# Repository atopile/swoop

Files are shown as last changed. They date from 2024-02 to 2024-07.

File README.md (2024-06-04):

# swoop

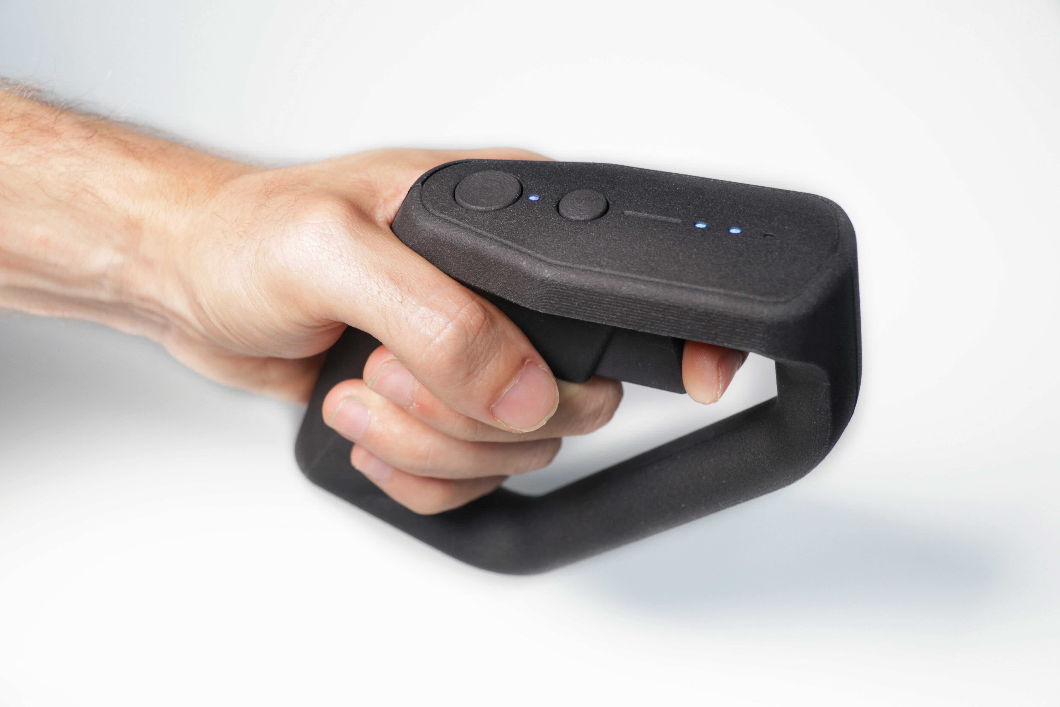
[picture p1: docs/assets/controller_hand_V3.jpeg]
controller and hand


<div align="center">
    <a href="#">
        
    </a>
    <a href="#">
        
    </a>
    <a href="#">
        
    </a>
    <a href="#">
        
    </a>
    <a href="#">
        
    </a>
</div>

## What is swoop🛫?

With swoop, you can fly remote controlled aircraft with the motion of your hand. It's especially fun when flying FPV because the motion of your remote precisely maps to the aircraft.

## Build your own controller

This project is fully open source and designed with [atopile](https://github.com/atopile/atopile), a new language and compiler to design electronics with code.

**Latest auto-generated artifacts**

[Electronics: Gerbers, Bill of material, position files](https://atopile.s3.amazonaws.com/swoop/electronics/electronics_build_artifacts.zip)

[Firmware](https://atopile.s3.amazonaws.com/swoop/firmware/firmware_build_artifacts.zip)

[3D Files (STL, STEP files in the future)](https://atopile.s3.amazonaws.com/swoop/mechanics/3D_files.zip)

**Atopile code**

The atopile entry point is located [here](https://github.com/atopile/swoop/blob/main/elec/src/swoop.ato). Clone the repository and [install atopile](https://atopile.io/getting-started/) if you'd like to explore further.

## Here is how it works:

The three rotation axis, yaw, pitch, roll of the remote each control the same channel on your aircraft. If you tilt your remote to a certain angle, your aircraft will rotate in that same direction with a certain rotational speed. That's what makes this controller so intuitive to use!
To start using the remote, simply double click the arming button (the larger button). This will zero the controller to the current position and start streaming the control outputs to the receiver.

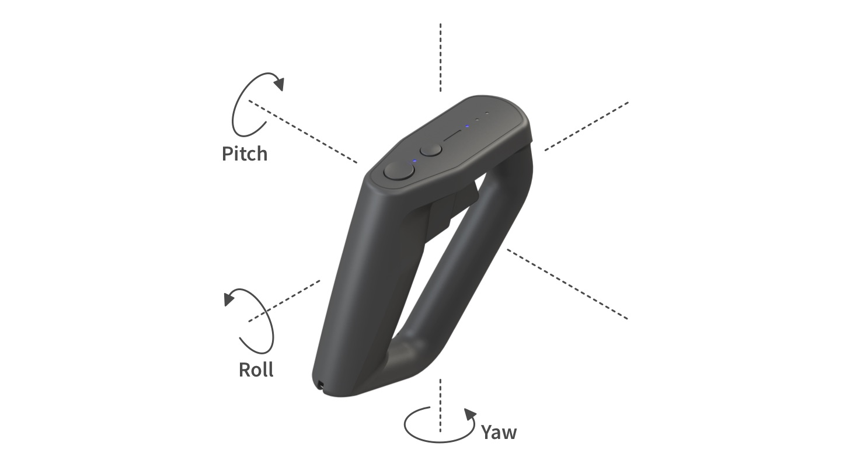
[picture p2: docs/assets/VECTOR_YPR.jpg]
yaw, pitch, roll


To control the throttle, which is your aircraft's motor power, simply press the trigger. Inside the controller, a hall sensor precisely keeps track of the trigger position. This makes for a total of four control inputs with yaw, pitch, roll and throttle.

The smaller button on the remote let's you switch the flight mode. Pretty handy to tweak how your aircraft reacts to your control inputs!

Lastly, the remote has an integrated transceiver from the popular open source ExpressLRS project, which makes it compatible with any of their receivers!

## Feature list

Here is what we are planning for this controller:

- Yaw, pitch and roll control angles from the motion of your hand
- Throttle control through the trigger
- Arming button (sets zero position and turn control inputs on/off)
- Flight mode button
- Embedded ExpressLRS transceiver
- Rechargeable over USB-C

## Documentation & Status

We will share documentation once we've made more progress on the project development. For current status, checkout the [product page](https://atopile.io/swoop/).

## Join us!

### Discord

If you are curious about the project, join us on the [atopile discord server](https://discord.gg/nr5V3QRUd3).

### Contributing

If you would like to contribute on atopile, here is what you will need:

For electronics:
- [atopile](https://atopile.io): here is a guide on how to install it: https://atopile.io/getting-started/
- [ExpressLRS](https://www.expresslrs.org): ELRS is an open source long range communication protocol for remote controlled aircraft. If you would like to test the remote, having compatible hardware will help!

For firmware:
- [PlatformIO](https://platformio.org): Cross platform firmware development toolchain
- [CRSF for Arduino](https://github.com/ZZ-Cat/CRSFforArduino): Implementation of the CRSF protocol for arduino. We'll be running this library to stream data from the controller microcontroller to the EzpressLRS module
- [ExpressLRS](https://www.expresslrs.org): ELRS is an open source long range communication protocol for remote controlled aircraft. Their firmware will be flashed on the embedded ESP32S2 module within the controller.

## Happy Flying!

swoop_test

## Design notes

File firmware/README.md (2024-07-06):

# Setup instructions

## Windows

1. Install git by running the following command in a terminal winow: `winget install Git.Git`
1. [Enable long paths both on the operating system and git level](https://arduino-pico.readthedocs.io/en/latest/platformio.html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)
1. Clone the repository e.g. using `git clone https://github.com/atopile/swoop.git`
1. Install [Visual Studio Code](https://code.visualstudio.com/)
1. Install [PlatformIO IDE Extension](https://platformio.org/install/ide?install=vscode)
1. Reopen Visual Studio Code and open the folder of the repository, it will install all dependencies
1. Donwload [Zadig](https://zadig.akeo.ie/) and install the WinUSB driver for the connected "RP2 Boot" device when Swoop is connected over USB
Zadig window Installing WinUSB using Zadig
1. At the bottom left of the window you find buttons for building, uploading, serial telemetry

## Mac

1. Install git e.g. via [Homebrew](https://brew.sh/) using `brew install git` ([formula](https://formulae.brew.sh/formula/git))
1. Clone Repository ´git clone https://github.com/atopile/swoop.git´
1. Install [Visual Studio Code](https://code.visualstudio.com/) Hombrew command: `brew install --cask visual-studio-code` ([formula](https://formulae.brew.sh/cask/visual-studio-code))
1. Install [PlatformIO Visual Studio Code Extension](https://marketplace.visualstudio.com/items?itemName=platformio.platformio-ide)
1. Reopen Visual Studio Code and open the folder of the repository, it will install all dependencies
1. At the bottom left of the window you find buttons for building, uploading, serial telemetry

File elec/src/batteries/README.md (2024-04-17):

# Battery connections

## Installation
Run in the terminal:

```ato install batteries```

Add the battery connectors to your project:

```import BatteryJST from "batteries/batteries.ato"```
```import Battery18650 from "batteries/batteries.ato"```
```import BatteryCR2032 from "batteries/batteries.ato"```

Feel free to add other battery modules to the repo through a pull request!

## 18650 holder
![18650 holder](https://assets.lcsc.com/images/lcsc/900x900/20230121_MYOUNG-BH-18650-A1AJ005_C5290176_front.jpg)

## JST GH Connector
![jst_gh](https://assets.lcsc.com/images/lcsc/900x900/20230108_JST-S2B-PH-SM4-TB-LF-SN_C295747_front.jpg)

## Coin cell holder
![coin cell](https://assets.lcsc.com/images/lcsc/900x900/20230105_MYOUNG-BS-02-A1AJ010_C5239862_front.jpg)

## Features

- **Power interface:** Hook the battery up to your circuit

## Documentation & Resources

- [LCSC part number for the 18650 holder](https://www.lcsc.com/product-detail/Battery-Connectors_MYOUNG-BH-18650-A1AJ005_C5290176.html)
- [LCSC part number for the JST GH connector](https://www.lcsc.com/product-detail/Wire-To-Board-Wire-To-Wire-Connector_JST-S2B-PH-SM4-TB-LF-SN_C295747.html)
- [LCSC part number for the coin cell holder](https://www.lcsc.com/product-detail/Battery-Connectors_MYOUNG-BS-02-A1AJ010_C5239862.html)

## Contributing

Contribute to this package using pull requests.

## License

This battery connector module is provided under the [MIT License](https://opensource.org/license/mit/).

## Contact

For further inquiries or support, please contact me at [narayan@atopile.io](mailto:narayan@atopile.io).

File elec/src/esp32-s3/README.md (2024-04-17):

## Overview

The ESP32-S3 is a powerful, versatile microcontroller designed for IoT applications. It features dual-core Xtensa LX7 processors, Wi-Fi and Bluetooth 5 connectivity, rich I/O capabilities, and enhanced security features, making it ideal for smart home devices, wearable electronics, and automated systems requiring efficient processing and wireless communication.

ESP32-S3

## Usage Example

```
import ESP32 from "esp32/esp32.ato"
import Power from "generics/interfaces.ato"

module my_project:
   power3v3 = new Power
   micro = new ESP32
   micro.power ~ power3v3

```

## Features
Power interface: 3.3V input
SPI interface: 4-wire SPI
I2C interface
JTAG interface

## Contributing
Contribute to this package using pull requests.

## License
This battery connector module is provided under the MIT License.

## Contact
For further inquiries or support, please contact me at narayan@atopile.io.

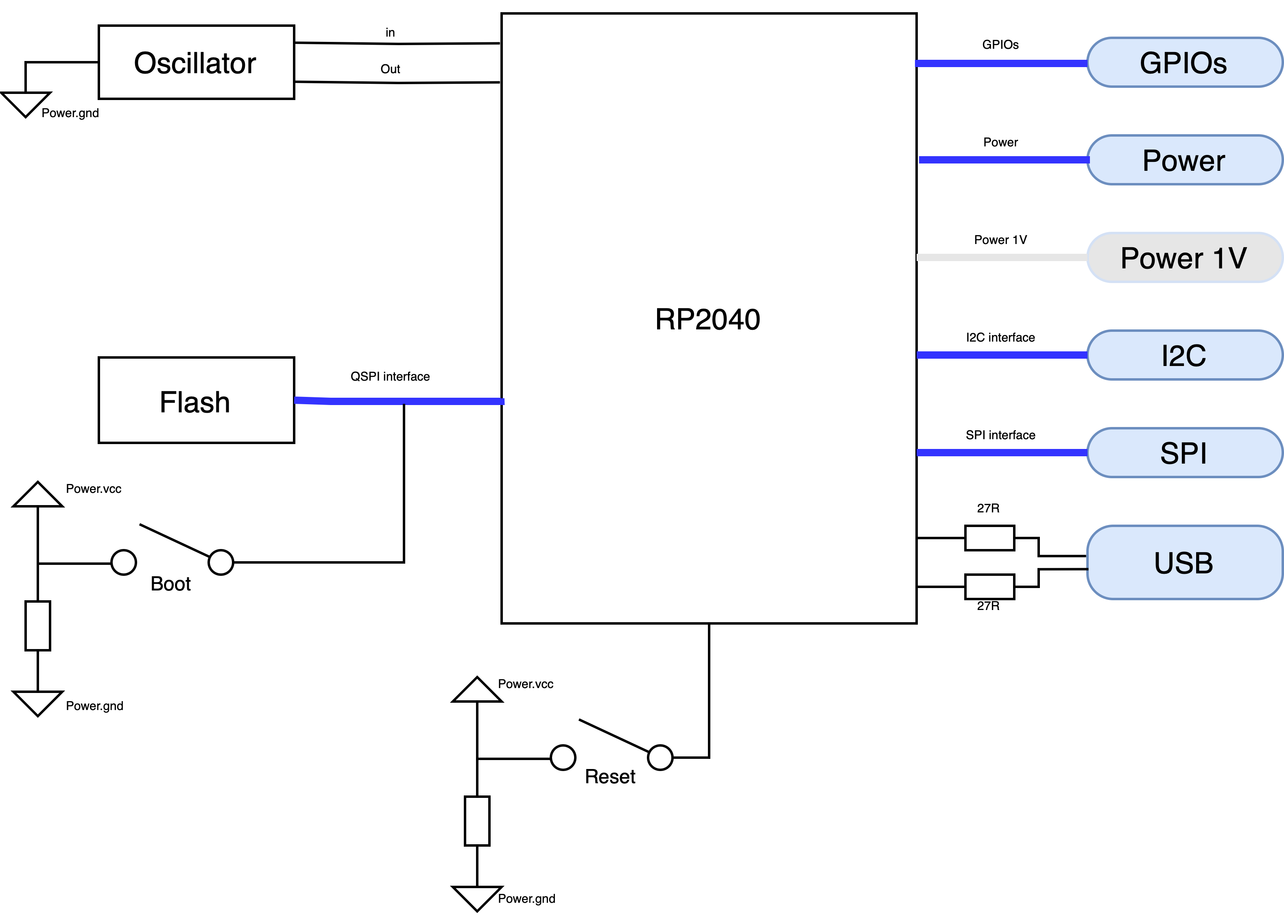
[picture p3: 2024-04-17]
elec/src/rp2040/docs/rp2040Kit.png

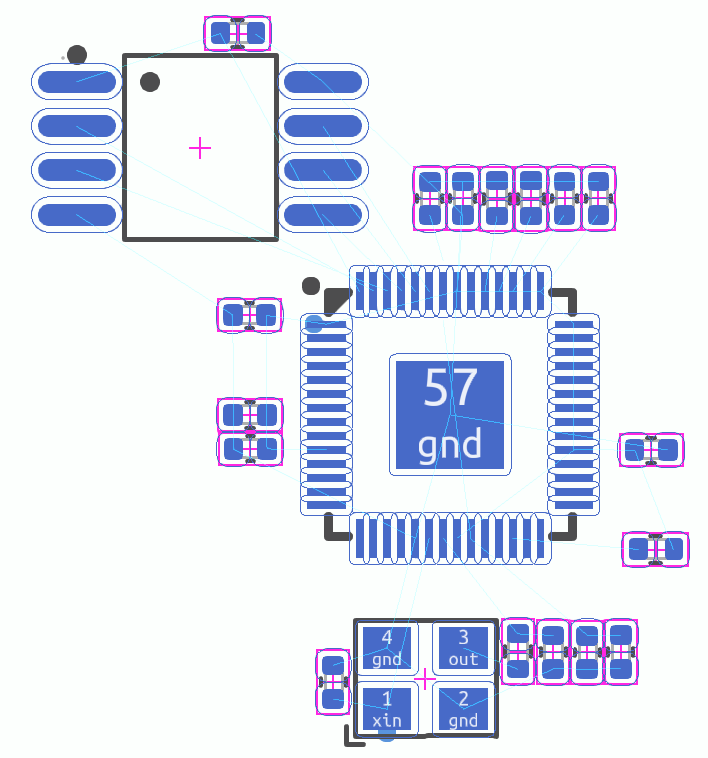
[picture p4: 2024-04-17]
elec/src/rp2040/docs/layout-example.png

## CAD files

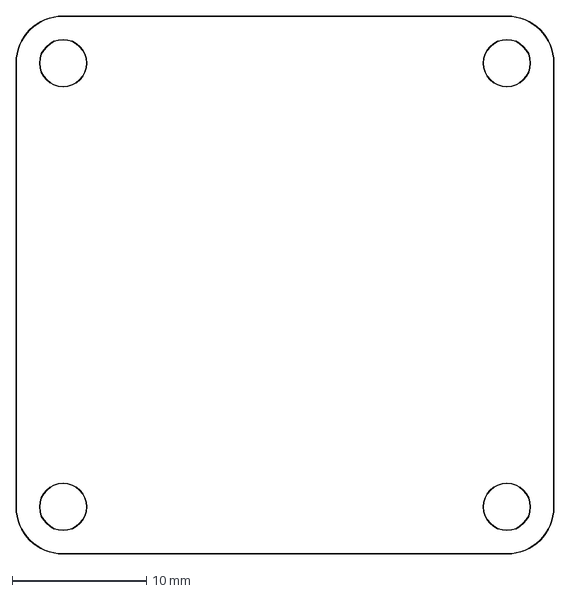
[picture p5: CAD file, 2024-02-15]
elec/src/drv5053raqdbzr/mech/template_outline.dxf
40.0 x 40.0 mm

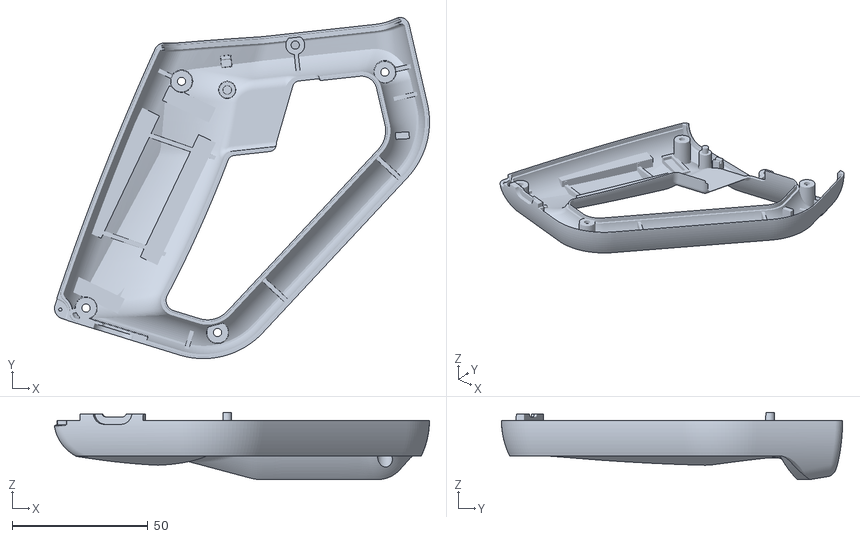
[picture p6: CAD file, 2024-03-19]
mech/shell_left.stl
138.2 x 125.8 x 24.9

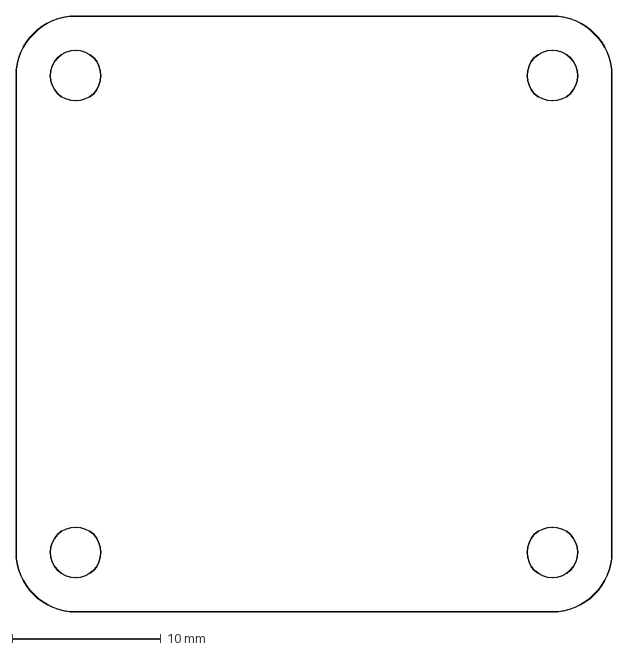
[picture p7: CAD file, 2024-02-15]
elec/src/drv5053raqdbzr/mech/template_40x40.dxf
40.0 x 40.0 mm

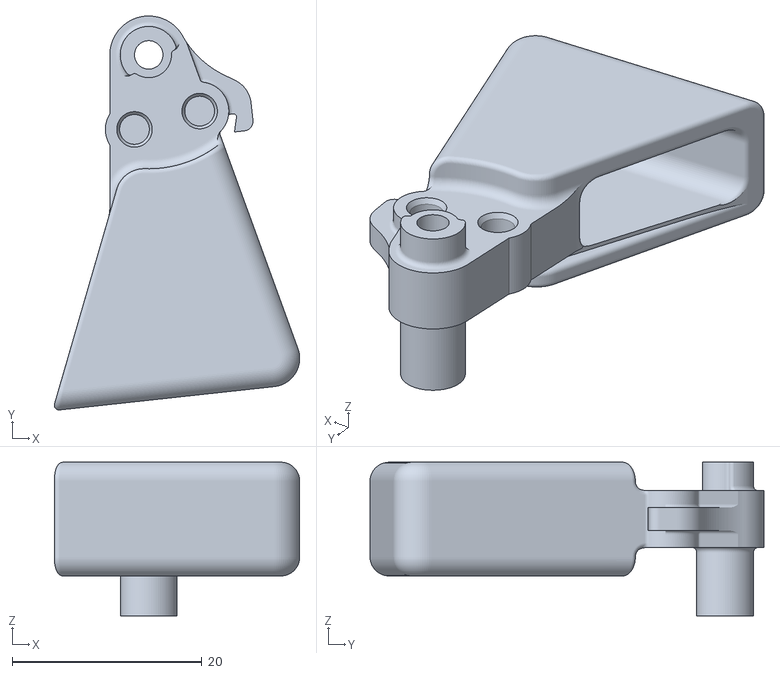
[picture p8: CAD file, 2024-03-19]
mech/trigger.stl
25.9 x 41.5 x 16.2

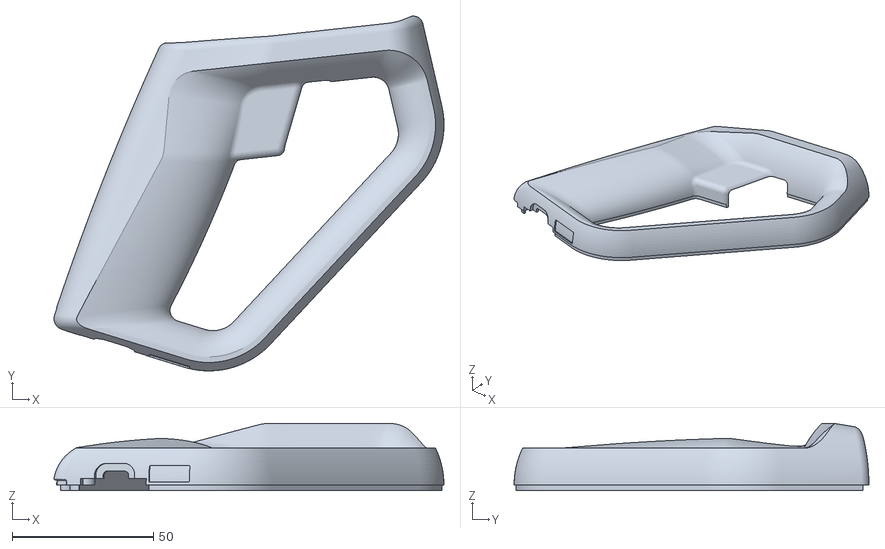
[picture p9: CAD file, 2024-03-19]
mech/Shell_right.stl
138.2 x 125.8 x 23.9

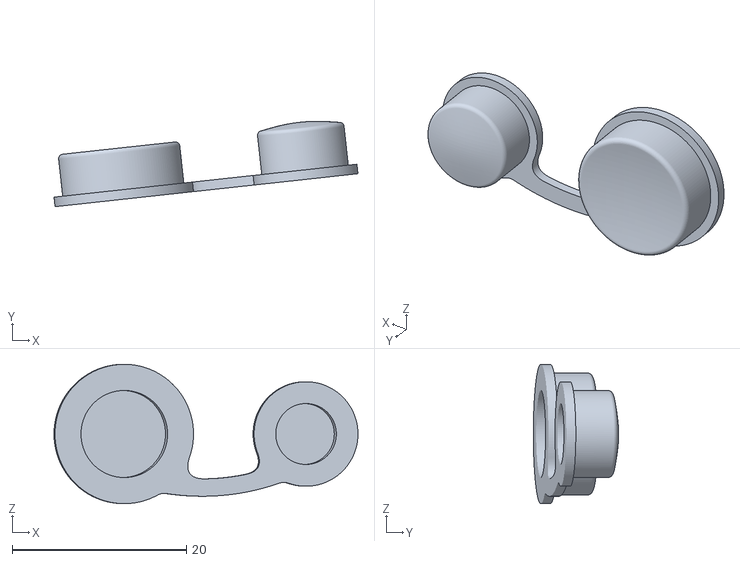
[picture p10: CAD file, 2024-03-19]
mech/buttons.stl
34.9 x 9.80 x 16.0

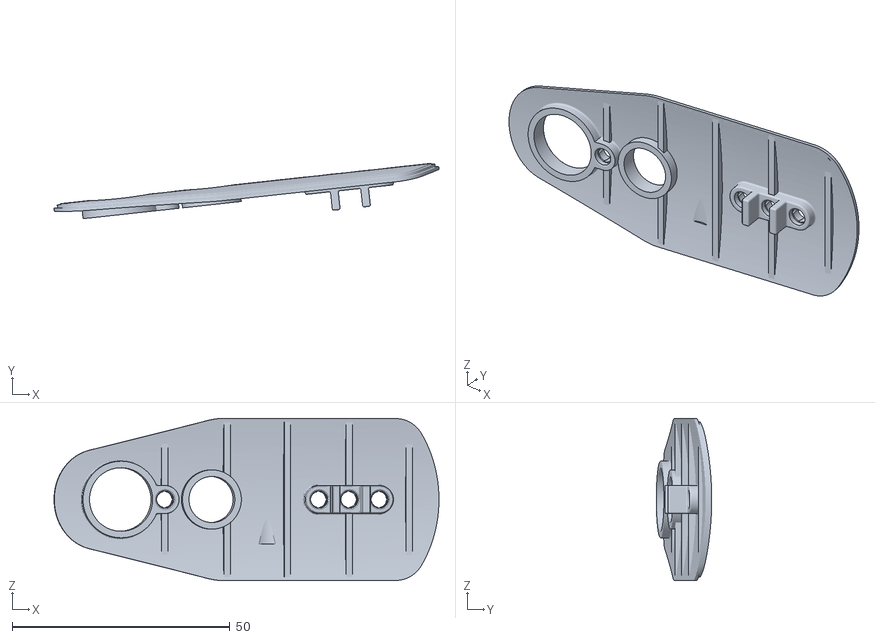
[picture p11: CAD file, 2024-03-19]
mech/top.stl
88.5 x 12.7 x 37.3

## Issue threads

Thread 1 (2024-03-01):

I2C Pull-up is too soft

mawildoer, 2024-03-01:
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

napowderly, 2024-04-25:
fixed in new rev

Closed 2024-04-25.

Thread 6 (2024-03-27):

Power management sucks

napowderly, 2024-03-27:
- Cannot recover from dead battery, batteries BMS shuts down, charger wont bring the rail up from 0V
- No low power sleep mode - all the rails up all the time.

napowderly, 2024-04-25:
fixed with pico-power module

Closed 2024-04-25.

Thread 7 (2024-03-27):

Trigger is clashing with the buttons

Timot05, 2024-03-27:
We need to move either move the button backwards or push the magnets and sensor forwards to prevent the clash.

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

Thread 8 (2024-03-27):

Add math for conversion of quaternion into yaw, pitch, roll control outputs

Timot05, 2024-03-27:
The sensor fusion should produce a quaternion representing the attitude of the controller. From there, we should be able to reset the quaternion's position to zero once we arm the controller. The yaw, pitch and roll angles should be extracted from the quaternion and sent over to the transceiver.

Closed 2024-03-27.

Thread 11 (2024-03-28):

IMU validation

napowderly, 2024-03-28:
- Confirm communication
- Read values + confirm they seem mildly sensible

napowderly, 2024-03-29:
BMI088 (IMU)
Not initializing properly, still.

BNO086 (IMU + mag)
Glitchy behavior

MPU6050 (IMU)
Working

LIS3DLTR (mag)
Working

Trace from MPU and LIS3DLTR:
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

Closed 2024-04-25.

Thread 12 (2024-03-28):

Trigger validation

napowderly, 2024-03-28:
Objective: Test trigger senses full throttle range

Graph of testing:
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

Noticed the first ~ 20% of travel is in a deadzone, need to adjust sensor position/magnet position.

Closed 2024-04-25.

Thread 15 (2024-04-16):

Aligning the mag, accel and gyro sensor axis

Timot05, 2024-04-16:
Using this issue to document the mag, accel and gyro sensor axis alignement.

Timot05, 2024-04-16:
From graphing the output sensor values from experiment, we have:
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

-> data is for LIS3MDLTR and MPU6500

Timot05, 2024-04-16:
[MPU6500 datasheet](https://www.cdiweb.com/datasheets/invensense/mpu_6500_rev1.0.pdf)
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

[LIS3MDL datasheet](https://www.st.com/resource/en/datasheet/lis3mdl.pdf)
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

MaEtUgR, 2024-04-16:
Thanks for the info. I can give this a go once I'm vack at the keyboard next week. Luckily I spent quite some time with these sensors on drone programming 😅

Timot05, 2024-04-23:
Nice! I've updated the math here and added the extraction of control angles. Everything lives in python at the moment so we'll have to port it over to C for the RP2040 micro once we are happy with it: https://github.com/atopile/swoop/pull/17

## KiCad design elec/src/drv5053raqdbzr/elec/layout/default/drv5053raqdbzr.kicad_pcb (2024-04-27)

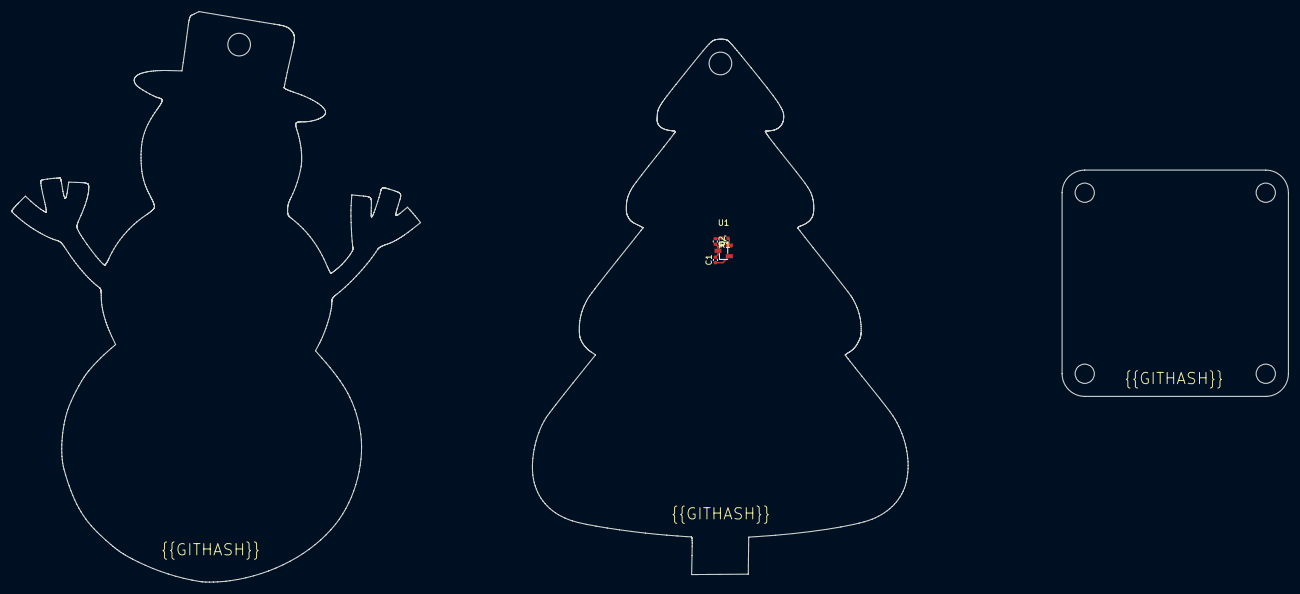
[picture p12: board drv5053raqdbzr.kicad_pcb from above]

Board: 2 copper layers, 66.4 x 94.6 mm, 4 parts (0 on the bottom side), 4 nets.

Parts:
C1, C2: 16V 100nF X7R ±10% 0402 Multilayer Ceramic Capaci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; C0402
R1: 62.5mW Thick Film Resistors ±100ppm/℃ ±1% 3.24kΩ 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; R0402
U1: SOT-23-3_L2.9-W1.3-P0.95-LS2.4-BR

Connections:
gnd: C1.2, C2.2, U1.3
ic-vcc: R1.1, U1.2
vcc: C1.1, U1.1
vcc-1: C2.1, R1.2

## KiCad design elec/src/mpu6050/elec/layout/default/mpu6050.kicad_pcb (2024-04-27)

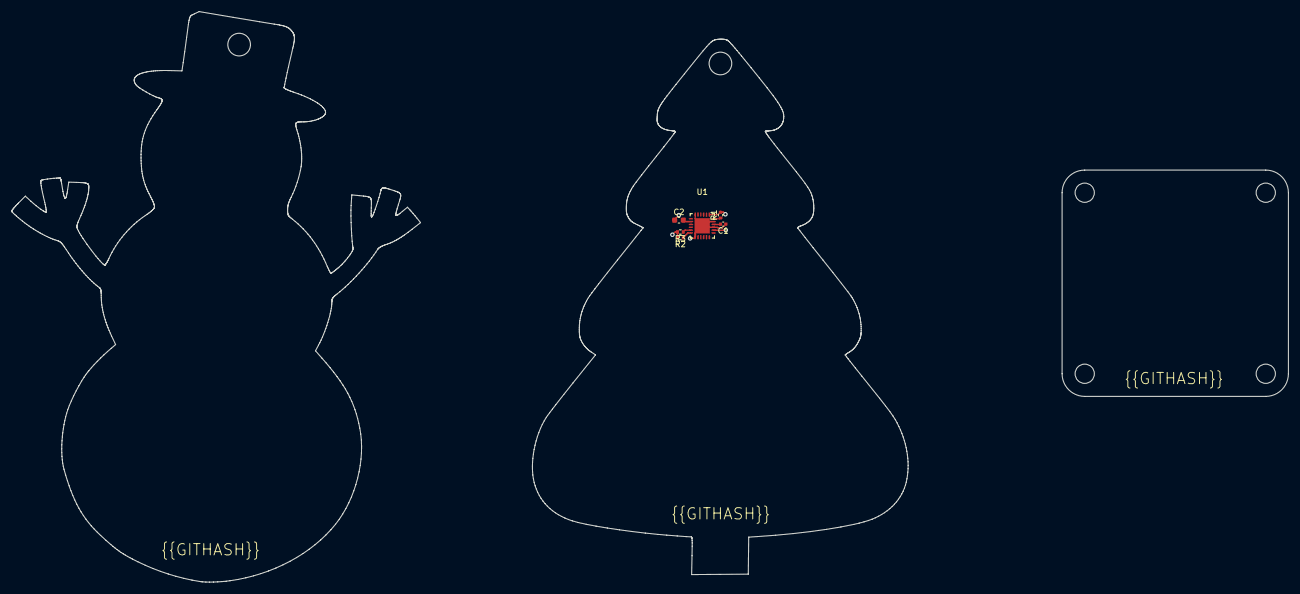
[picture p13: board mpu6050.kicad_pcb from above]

Board: 2 copper layers, 66.4 x 94.6 mm, 6 parts (0 on the bottom side), 7 nets.

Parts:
C1: 16V 100nF X7R ±10% 0402 Multilayer Ceramic Capaci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; C0402
C2: 50V 2.2nF X7R ±10% 0603 Multilayer Ceramic Capaci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; C0603
R1, R2, R3: 62.5mW Thick Film Resistors ±100ppm/℃ ±1% 10kΩ 04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; R0402
U1: QFN-24_L4.0-W4.0-P0.50-BL-EP2.7

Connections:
cpout: C2.2, U1.20
gnd-1: C1.1, C2.1, U1.1, U1.9, U1.11, U1.18, U1.25
interrupt: R1.1, U1.12
regout: C1.2, U1.10
scl: R3.1, U1.23
sda: R2.1, U1.24
vcc: R1.2, R2.2, R3.2, U1.8, U1.13

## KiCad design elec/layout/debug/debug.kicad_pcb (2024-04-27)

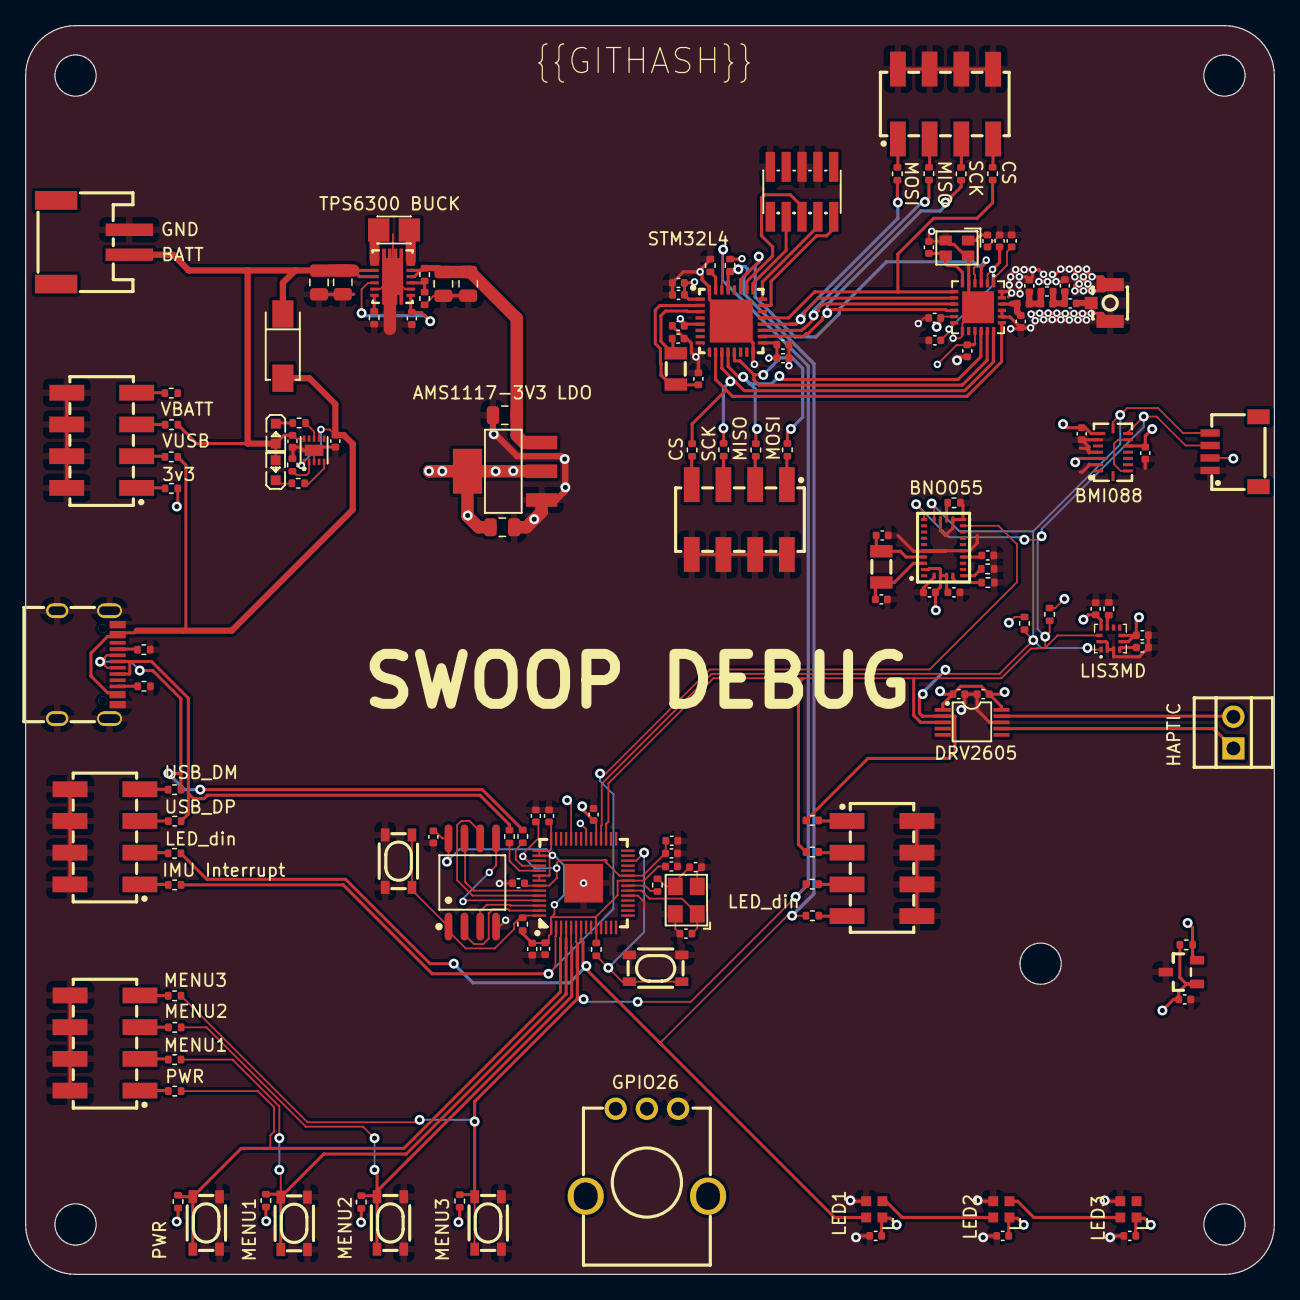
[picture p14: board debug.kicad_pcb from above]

Board: 4 copper layers, 100.0 x 100.0 mm, 150 parts (0 on the bottom side), 103 nets.

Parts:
C1, C2: 50V 20pF C0G ±5% 0402 Multilayer Ceramic Capacito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; C0402
C3, C4, C5, C6, C7, C9, C10, C11, C19, C22, C24, C27, C28, C29, C31, C33, C35, C42, C43, C51, C52, C53, C54: 16V 100nF X7R ±10% 0402 Multilayer Ceramic Capaci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; C0402
C8, C12, C13, C14, C23, C30, C34, C55, C56: 25V 1uF X5R ±10% 0402 Multilayer Ceramic Capacito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; C0402
C15, C16, C17, C18, C20, C21: 25V 10uF X5R ±10% 0805 Multilayer Ceramic Capacit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; C0805
C25, C26: 50V 22pF C0G ±5% 0402 Multilayer Ceramic Capacito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; C0402
C32: 10V 4.7uF X5R ±20% 0402 Multilayer Ceramic Capaci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; C0402
C36, C44, C45: 50V 10nF X7R ±10% 0402 Multilayer Ceramic Capacit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; C0402
C37, C38: 50V 13pF C0G ±2% 0402 Multilayer Ceramic Capacito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; C0402
C39, C40: 50V 11pF C0G ±5% 0402 Multilayer Ceramic Capacito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; C0402
C41: 10V 470nF X5R ±10% 0402 Multilayer Ceramic Capaci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; C0402
C46, C47, C48, C49: 50V 1pF C0G 0402 Multilayer Ceramic Capacitors ML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; C0402
C50: 50V 100pF C0G ±5% 0402 Multilayer Ceramic Capacit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; C0402
D1: SMA_L4.2-W2.6-LS5.3-RD
J1: CONN-SMD_4P-P1.00_SM04B-SRSS-TB-LF-SN
L1: IND-SMD_L2.5-W2.0_WPN252012H
L2, L3: L0402
LED1, LED2: LED0603-RD
R1, R2, R6, R7, R14, R15, R16, R19, R22, R23, R24, R25: 62.5mW Thick Film Resistors ±100ppm/℃ ±1% 10kΩ 04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; R0402
R3, R17, R26, R27, R28, R29, R30, R31, R32, R33, R34, R35, R36, R37, R38, R39, R40, R41, R42, R43, R44, R45, R46, R47, R48, R49, R50: 62.5mW Thick Film Resistors ±100ppm/℃ ±1% 1kΩ 040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; R0402
R4, R5: 62.5mW Thick Film Resistors ±100ppm/℃ ±1% 27kΩ 04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; R0402
R8: 62.5mW Thick Film Resistors ±100ppm/℃ ±1% 510Ω 04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; R0402
R9: 62.5mW Thin Film Resistor ±0.5% ±25ppm/℃ 110Ω 040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; R0402
R10: 62.5mW Thick Film Resistors ±100ppm/℃ ±1% 82Ω 040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; R0402
R11: 100mW Thick Film Resistors ±5% ±200ppm/℃ 1.1MΩ 04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; R0402
R12: 62.5mW Thick Film Resistors ±100ppm/℃ ±1% 180kΩ 0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; R0402
R13: 62.5mW Thick Film Resistors ±100ppm/℃ ±1% 1MΩ 040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; R0402
R18: 62.5mW Thick Film Resistors ±100ppm/℃ ±1% 330Ω 04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; R0402
R20, R21: 62.5mW Thick Film Resistors ±100ppm/℃ ±1% 5.1kΩ 0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; R0402
U1: LQFN-56_L7.0-W7.0-P0.4-EP
U2: OSC-SMD_4P-L3.2-W2.5-BL
U3: SOIC-8_L5.3-W5.3-P1.27-LS8.0-BL
U4, U5, U24, U25, U26, U27: KEY-SMD_4P-L4.2-W3.2-P2.20-LS4.6
U6: CONN-SMD_P2.00_S2B-PH-SM4-TB-LF-SN
U7: WSON-10_L2.0-W2.0-P0.40-BL-EP
U8: VSON-14_L4.0-W3.0-P0.50-BL-EP_TI_DSJ
U9: SOT-223-3_L6.5-W3.4-P2.30-LS7.0-BR
U10: LGA-28_L5.2-W3.8-P0.50-BL
U11, U15: FC-135R_L3.2-W1.5
U12: LGA-16_L4.5-W3.0-P0.50-BL
U13: LGA-12_L2.0-W2.0-P0.50-BL
U14: UFQFPN-32_L5.0-W5.0-P0.50-TL-EP3.5
U16: QFN-24_L4.0-W4.0-P0.50-BL-EP2.6
U17: OSC-SMD_4P-L2.0-W1.6-BL
U18: IPEX-SMD_BWIPX-1-001E
U19: HDR-SMD_10P-P1.27-V-M-R2-C5-LS5.3
U20: USB-C-SMD_KH-TYPE-C-16P
U21, U22, U23: LED-SMD_4P-L2.0-W2.0-BR
U28: SOT-23-3_L2.9-W1.3-P1.90-LS2.4-BR-CW
U29: VSSOP-10_L3.0-W3.0-P0.50-LS4.9-BL
U30: CONN-TH_DB125-2.54-2P-GN
U31, U32, U33, U34, U35, U36: HDR-SMD_8P-P2.54-V-M-R2-C4-LS7.4
U37: RES-ADJ-TH_RK09K1130AJ3

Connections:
_1: R27.2, U31.1
_1-1: R31.2, U32.1
_1-2: R35.2, U33.1
_1-3: R39.2, U34.1
_1-4: R43.2, U35.1
_1-5: R47.2, U36.1
_3: R28.2, U31.3
_3-1: R32.2, U32.3
_3-2: R36.2, U33.3
_3-3: R40.2, U34.3
_3-4: R44.2, U35.3
_3-5: R48.2, U36.3
_5: R29.2, U31.5
_5-1: R33.2, U32.5
_5-2: R37.2, U33.5
_5-3: R41.2, U34.5
_5-4: R45.2, U35.5
_5-5: R49.2, U36.5
_7-1: R30.2, U31.7
_7-2: R34.2, U32.7
_7-3: R38.2, U33.7
_7-4: R42.2, U34.7
_7-5: R46.2, U35.7
_7-6: R50.2, U36.7
c1: C29.1, U13.4
cap: C24.1, U10.9
cathode: LED1.1, R9.1
cathode-1: LED2.1, R10.1
cc1: R20.1, U20.A5
cc2: R21.1, U20.B5
com3: R14.1, U10.17
cs: R7.2, U1.56, U3.1, U5.1, U5.2
cs-2: R46.1, U14.10, U16.19
dm: R5.1, R34.1, U20.A7, U20.B7
dp: R4.2, R33.1, U20.A6, U20.B6
gnd: C1.2, C2.2, C3.2, C4.2, C5.2, C6.2, C7.2, C8.2, C9.2, C10.2, C11.2, C12.2, C13.2, C14.2, C15.2, C16.2, C17.2, C18.2, C19.2, C20.2, C21.2, C22.2, C23.2, C24.2, C25.2, C26.2, C27.2, C28.2, C29.2, C30.2, C31.2, C32.2, C33.2, C34.2, C35.2, C36.2, C37.2, C38.2, C39.2, C40.2, C41.2, C42.2, C43.2, C44.2, C45.2, C46.2, C47.2, C48.2, C51.2, C52.2, C53.2, C54.2, C55.2, C56.2, J1.1, R8.2, R12.2, R13.2, R14.2, R15.2, R16.2, R17.2, R19.2, R20.2, R21.2, U1.19, U1.57, U2.2, U2.4, U3.4, U4.3, U4.4, U5.3, U5.4, U6.1, U7.3, U7.11, U8.2, U8.13, U8.15, U9.1, U10.2, U10.10, U10.15, U10.16, U10.18, U10.25, U12.2, U12.4, U12.6, U13.2, U13.3, U13.12, U14.16, U14.32, U14.33, U16.5, U16.13, U16.20, U16.21, U16.23, U16.24, U16.25, U17.2, U17.4, U18.2, U18.3, U19.3, U19.5, U19.9, U20.1, U20.2, U20.3, U20.4, U20.A1, U20.A12, U20.B1, U20.B12, U21.3, U22.3, U23.3, U24.3, U24.4, U25.3, U25.4, U26.3, U26.4, U27.3, U27.4, U28.2, U29.8, U31.2, U31.4, U31.6, U31.8, U32.2, U32.4, U32.6, U32.8, U33.2, U33.4, U33.6, U33.8, U34.2, U34.4, U34.6, U34.8, U35.2, U35.4, U35.6, U35.8, U36.2, U36.4, U36.6, U36.8, U37.1
gnd-4: R9.2, U7.5
gnd-5: R10.2, U7.8
gnd-10: C50.2, U18.1
io: U1.35, U37.2
io0: U1.53, U3.5
io1: U1.55, U3.2
io2: U1.54, U3.3
io3: U1.51, U3.7
io-1: U14.27, U16.3
io-2: C46.1, L2.1, U16.22
iset: R8.1, U7.2
l1: L1.1, U8.8, U8.9
l2: L1.2, U8.6, U8.7
miso-1: R17.1, U13.9
miso-2: R44.1, U14.12, U16.16
mosi-1: R43.1, U14.13, U16.17
n: U29.9, U30.2
out: C2.1, R3.2, U2.3
out-1: R11.2, R12.1, U8.3
p: U29.7, U30.1
pc14_osc32_in: C37.1, U14.2, U15.1
pc15_osc32_out: C38.1, U14.3, U15.2
pg: R13.1, U8.14
ph3_boot0: R19.1, U14.31
ps0: R15.1, U10.6
ps1: R16.1, U10.5
run: R6.2, U1.26, U4.1, U4.2
sck: U1.52, U3.6
sck-2: R45.1, U14.11, U16.18
scl: J1.4, R2.1, R27.1, U1.32, U10.19, U12.8, U13.1, U29.2
sda: J1.3, R1.1, R28.1, U1.31, U10.20, U12.9, U13.11, U29.3
sdo2: U12.10, U12.15
tck: U14.24, U19.4
tdi: U14.25, U19.8
tdo: U14.26, U19.6
tms: U14.23, U19.2
usb_dm: R5.2, U1.46
usb_dp: R4.1, U1.47
vcc: C3.1, C4.1, C5.1, C6.1, C7.1, C8.1, C21.1, C22.1, C23.1, C27.1, C28.1, C30.1, C31.1, C32.1, C33.1, C34.1, C35.1, C36.1, C42.1, C43.1, C51.1, C52.1, C53.1, C54.1, C55.1, C56.1, J1.2, R1.2, R2.2, R6.1, R7.1, R18.2, R22.1, R23.1, R24.1, R25.1, R26.1, R39.1, U1.1, U1.10, U1.22, U1.33, U1.42, U1.43, U1.44, U1.48, U1.49, U3.8, U9.2, U9.4, U10.3, U10.4, U10.28, U12.3, U12.7, U12.11, U13.5, U13.6, U13.10, U14.1, U14.5, U14.17, U16.11, U16.15, U21.1, U22.1, U23.1, U28.1, U29.1, U29.10, U37.3
vcc-1: R25.2, R29.1, R38.1, U1.6, U14.30, U27.1, U27.2
vcc-2: R18.1, R30.1, R32.1, U1.7, U14.29, U21.4
vcc-3: R31.1, U1.2, U10.14
vcc-4: R22.2, R35.1, U1.3, U24.1, U24.2
vcc-5: R23.2, R36.1, U1.4, U25.1, U25.2
vcc-6: R24.2, R37.1, U1.5, U26.1, U26.2
vcc-7: R26.2, U1.38, U28.3
vcc-8: C9.1, C10.1, C11.1, C12.1, U1.23, U1.45, U1.50
vcc-9: C13.1, D1.2, R40.1, U7.1, U7.7, U20.A4, U20.A9, U20.B4, U20.B9
vcc-10: C14.1, C15.1, C16.1, D1.1, LED1.2, LED2.2, R41.1, U6.2, U7.10, U8.10, U8.11
vcc-13: C17.1, C18.1, C20.1, R11.1, U8.4, U8.5, U9.3
vcc-14: R49.1, U14.18, U16.10
vcc-15: R48.1, U14.19, U16.9
vcc-16: R47.1, U14.20, U16.8
vcc-17: R50.1, U14.21, U16.7
vcc-19: C45.1, U16.1
vcc-20: C41.1, C44.1, U16.2, U16.12
vcc-22: C47.1, C49.1, L2.2, L3.1
vcc-23: C48.1, C49.2, C50.1, L3.2
vcc-25: U21.2, U22.4
vcc-26: U22.2, U23.4
vina: C19.1, U8.1, U8.12
xin: C1.1, U1.20, U2.1
xin32: C25.1, U10.27, U11.1
xout: R3.1, U1.21
xout32: C26.1, U10.26, U11.2
xta: C39.1, U16.4, U17.1
xtb: C40.1, U16.6, U17.3

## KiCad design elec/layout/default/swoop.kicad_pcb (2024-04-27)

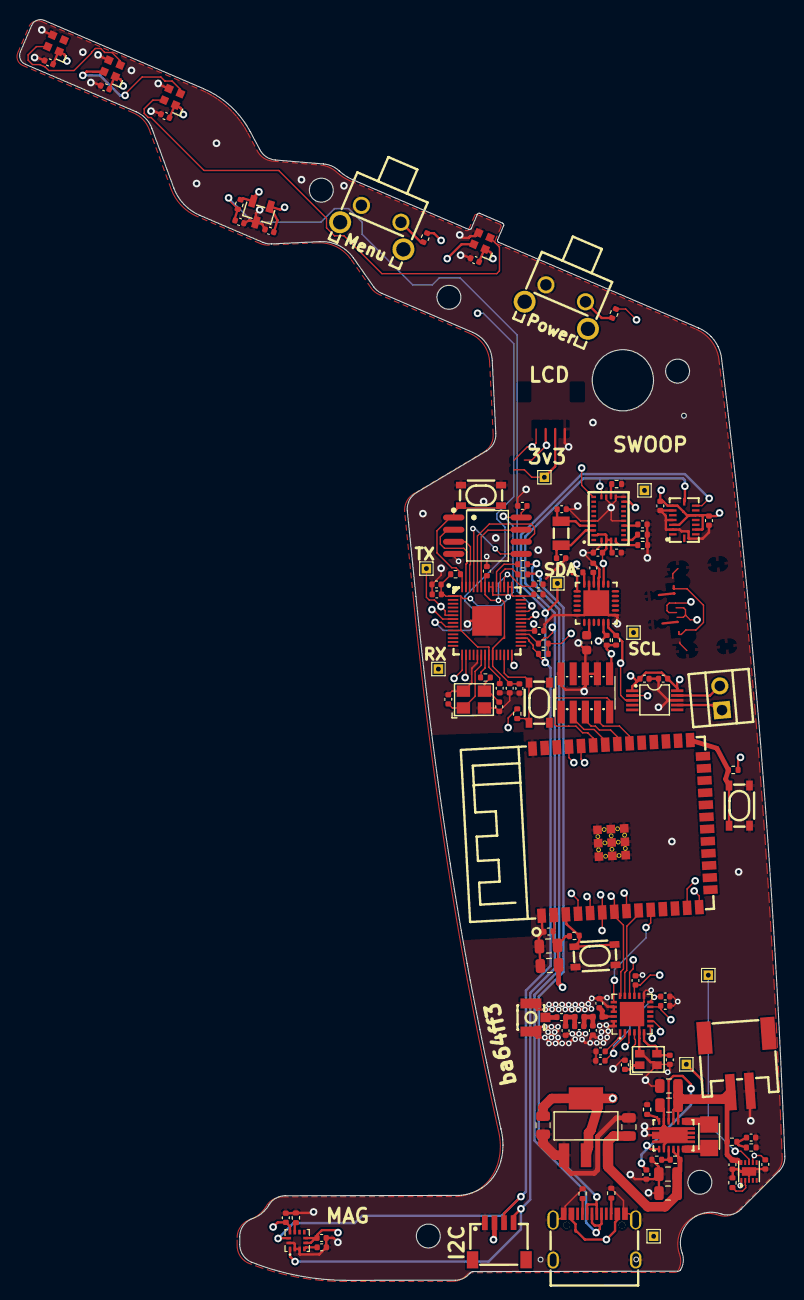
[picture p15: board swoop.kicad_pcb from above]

Board: 4 copper layers, 80.0 x 131.9 mm, 128 parts (0 on the bottom side), 78 nets.

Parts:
C1, C2, C26, C27: 50V 18pF C0G ±5% 0402 Multilayer Ceramic Capacito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; C0402
C3, C4, C5, C6, C7, C9, C10, C11, C19, C22, C23, C25, C28, C29, C30, C32, C34, C35, C41, C42, C50, C51, C52, C53, C54, C55: 16V 100nF X7R ±10% 0402 Multilayer Ceramic Capaci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; C0402
C8, C12, C13, C14, C24, C33, C56, C57: 25V 1uF X5R ±10% 0402 Multilayer Ceramic Capacito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; C0402
C15, C16, C17, C18, C20, C21, C36, C37: 25V 10uF X5R ±10% 0805 Multilayer Ceramic Capacit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; C0805
C31: 50V 2.2nF X7R ±10% 0603 Multilayer Ceramic Capaci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; C0603
C38, C39: 50V 12pF C0G ±5% 0402 Multilayer Ceramic Capacito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; C0402
C40: 50V 470nF X5R ±10% 0402 Multilayer Ceramic Capaci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; C0402
C43, C44: 50V 10nF X7R ±10% 0402 Multilayer Ceramic Capacit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; C0402
C45: 50V 0.8pF 0402 Multilayer Ceramic Capacitors MLCC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; C0402
C46, C47: 50V 1.2pF C0G 0402 Multilayer Ceramic Capacitors 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; C0402
C48: 50V 0.5pF C0G 0402 Multilayer Ceramic Capacitors 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; C0402
C49: 50V 100pF C0G ±5% 0402 Multilayer Ceramic Capacit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; C0402
J1: CONN-SMD_4P-P1.00_SM04B-SRSS-TB-LF-SN
L1: IND-SMD_L2.5-W2.0_WPN252012H
L2, L3: L0402
R1, R2, R14, R15, R16, R17, R18, R19, R21, R22, R25, R26: 62.5mW Thick Film Resistors 50V ±100ppm/℃ ±1% 10k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; R0402
R3, R20: 62.5mW Thick Film Resistors 50V ±100ppm/℃ ±1% 1kΩ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; R0402
R4, R5: 62.5mW Thick Film Resistors 50V ±100ppm/℃ ±1% 27Ω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; R0402
R6, R7: 62.5mW Thick Film Resistors 50V ±100ppm/℃ ±1% 2kΩ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; R0402
R8: 100mW Thick Film Resistors ±100ppm/℃ ±1% 1.07kΩ 0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; R0402
R9: 62.5mW Thick Film Resistors 50V ±100ppm/℃ ±1% 698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; R0402
R10: 62.5mW Thick Film Resistors 50V ±1% ±200ppm/℃ 105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; R0402
R11: 62.5mW Thick Film Resistors 50V ±100ppm/℃ ±1% 1MΩ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; R0402
R12: 62.5mW Thick Film Resistors 50V ±100ppm/℃ ±1% 16.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; R0402
R13: 62.5mW Thick Film Resistors 50V ±100ppm/℃ ±1% 17.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; R0402
R23, R24: 62.5mW Thick Film Resistors 50V ±100ppm/℃ ±1% 4.7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; R0402
R27: 62.5mW Thick Film Resistors ±100ppm/℃ ±1% 3.24kΩ 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; R0402
U1: LQFN-56_L7.0-W7.0-P0.4-EP
U2, U3, U25, U29: KEY-SMD_4P-L4.2-W3.2-P2.20-LS4.6
U4: OSC-SMD_4P-L3.2-W2.5-BL
U5: SOIC-8_L5.3-W5.3-P1.27-LS8.0-BL
U6, U7, U8, U9, U10, U15, U16, U17, U18: TestPoint_THTPad_1.0x1.0mm_Drill0.5mm
U11: CONN-SMD_P2.00_S2B-PH-SM4-TB-LF-SN
U12: WSON-10_L2.0-W2.0-P0.40-BL-EP
U13: VSON-14_L4.0-W3.0-P0.50-BL-EP_TI_DSJ
U14: SOT-223-3_L6.5-W3.4-P2.30-LS7.0-BR
U19: LGA-28_L5.2-W3.8-P0.50-BL
U20: FC-135R_L3.2-W1.5
U21: LGA-16_L4.5-W3.0-P0.50-BL
U22: QFN-24_L4.0-W4.0-P0.50-BL-EP2.7
U23: LGA-12_L2.0-W2.0-P0.50-BL
U24: WIRELM-SMD_ESP32-S3-WROOM-1
U26: QFN-24_L4.0-W4.0-P0.50-BL-EP2.6
U27: OSC-SMD_4P-L2.0-W1.6-BL
U28: IPEX-SMD_BWIPX-1-001E
U30: HDR-SMD_10P-P1.27-V-M-R2-C5-LS5.3
U31: USB-C-SMD_KH-TYPE-C-16P
U32, U33, U34, U35: LED-SMD_4P-L2.0-W2.0-BR
U36, U37: SW-TH_TS-1093C-A7B3-D1
U38: SOT-23-3_L2.9-W1.3-P0.95-LS2.4-BR
U39: VSSOP-10_L3.0-W3.0-P0.50-LS4.9-BL
U40: CONN-TH_DB125-2.54-2P-GN

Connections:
c1: C32.1, U23.4
cap: C25.1, U19.9
cc1: R23.1, U31.A5
cc2: R24.1, U31.B5
com3: R14.1, U19.17
cpout: C31.2, U22.20
dm: R5.1, U31.A7, U31.B7
dp: R4.2, U31.A6, U31.B6
gnd: C1.2, C2.2, C3.2, C4.2, C5.2, C6.2, C7.2, C8.2, C9.2, C10.2, C11.2, C12.2, C13.2, C14.2, C15.2, C16.2, C17.2, C18.2, C19.2, C20.2, C21.2, C22.2, C23.2, C24.2, C25.2, C26.2, C27.2, C28.2, C29.2, C30.1, C31.1, C32.2, C33.2, C34.2, C35.2, C36.2, C37.2, C38.2, C39.2, C40.2, C41.2, C42.2, C43.2, C44.2, C45.2, C46.2, C47.2, C50.2, C51.2, C52.2, C53.2, C54.2, C55.2, C56.2, C57.2, J1.1, R8.2, R10.2, R11.2, R13.2, R14.2, R15.2, R16.2, R20.2, R23.2, R24.2, U1.19, U1.57, U2.3, U2.4, U3.3, U3.4, U4.2, U4.4, U5.4, U11.1, U12.3, U12.11, U13.2, U13.13, U13.15, U14.1, U19.2, U19.10, U19.15, U19.16, U19.18, U19.25, U21.2, U21.4, U21.6, U22.1, U22.9, U22.11, U22.18, U22.25, U23.2, U23.3, U23.12, U24.1, U24.40, U24.41, U25.3, U25.4, U26.5, U26.13, U26.20, U26.21, U26.23, U26.24, U26.25, U27.2, U27.4, U28.2, U28.3, U29.3, U29.4, U30.3, U30.5, U30.9, U31.1, U31.2, U31.3, U31.4, U31.A1, U31.A12, U31.B1, U31.B12, U32.3, U33.3, U34.3, U35.3, U36.2, U37.2, U38.3, U39.8
imu.lis3mdltr.ic-miso: R20.1, U23.9
interrupt: R17.1, U22.12
io4: U24.4, U26.7
io5: U24.5, U26.8
io6: U24.6, U26.3
io7: U24.7, U26.18
io15: U24.8, U26.16
io16: U24.9, U26.17
io17: U24.10, U26.19
ios.hall_effect.ic-vcc: R27.1, U38.2
ios.led1.ic-vcc: U32.2, U33.4
ios.led2.ic-vcc: U33.2, U34.4
ios.led3.ic-vcc: U34.2, U35.4
iset: R8.1, U12.2
l1: L1.1, U13.8, U13.9
l2: L1.2, U13.6, U13.7
micro-vcc: U1.36, U10.1, U19.14
micro-vcc-1: R25.2, U1.15, U36.1
micro-vcc-2: R26.2, U1.16, U37.1
micro-vcc-3: U1.9, U32.4
micro-vcc-4: C55.1, R27.2, U1.38
micro-vcc-5: U1.28, U12.8, U18.1
micro.micro-cs-1: R2.2, U1.56, U3.1, U3.2, U5.1
micro.micro-io0: U1.53, U5.5
micro.micro-io1: U1.55, U5.2
micro.micro-io2: U1.54, U5.3
micro.micro-io3: U1.51, U5.7
micro.micro-sck-1: U1.52, U5.6
micro.micro.micro-vcc: C9.1, C10.1, C11.1, C12.1, U1.23, U1.45, U1.50
micro.micro.osc.osc-out: C2.1, R3.2, U4.3
n: U39.9, U40.2
p: U39.7, U40.1
power_supply-vcc: C13.1, U12.1, U12.7, U15.1, U31.A4, U31.A9, U31.B4, U31.B9
power_supply.battery-vcc: C14.1, C15.1, C16.1, R12.1, U11.2, U12.10, U13.10, U13.11, U17.1
power_supply.battery_voltage_sensor-out: C22.1, R12.2, R13.1
power_supply.buckboost-vcc: C17.1, C18.1, C20.1, R9.1, U13.4, U13.5, U14.3
power_supply.buckboost.tps_buck_boost.feedback_div-out: R9.2, R10.1, U13.3
power_supply.buckboost.tps_buck_boost.ic-pg: R11.1, U13.14
ps0: R15.1, U19.6
ps1: R16.1, U19.5
radio._micro.ic-en: R21.2, U24.3, U25.1, U25.2
radio._micro.ic-io0: R22.2, U24.27, U29.1, U29.2
radio._radio.decoupling_cap-gnd: C49.2, U28.1
radio._radio.ic-vcc: C44.1, U26.1
radio._radio.ic-vcc-1: C40.1, C43.1, U26.2, U26.12
radio._radio.ic-vcc-2: C45.1, L2.1, U26.22
radio._radio.matching_circuit-vcc: C46.1, C48.1, L2.2, L3.1
radio._radio.pi_filter-vcc: C47.1, C48.2, C49.1, L3.2
regout: C30.2, U22.10
run: R1.2, U1.26, U2.1, U2.2
rx: U1.7, U9.1, U24.37
scl: J1.4, R7.1, R19.1, U1.32, U6.1, U19.19, U21.8, U22.23, U23.1, U39.2
sda: J1.3, R6.1, R18.1, U1.31, U7.1, U19.20, U21.9, U22.24, U23.11, U39.3
sdo2: U21.10, U21.15
tck: U24.32, U30.4
tdi: U24.34, U30.8
tdo: U24.33, U30.6
tms: U24.35, U30.2
tx: U1.6, U8.1, U24.36
usb_dm: R5.2, U1.46
usb_dp: R4.1, U1.47
vcc: C3.1, C4.1, C5.1, C6.1, C7.1, C8.1, C21.1, C23.1, C24.1, C28.1, C29.1, C33.1, C34.1, C35.1, C36.1, C37.1, C41.1, C42.1, C50.1, C51.1, C52.1, C53.1, C54.1, C56.1, C57.1, J1.2, R1.1, R2.1, R6.2, R7.2, R17.2, R18.2, R19.2, R21.1, R22.1, R25.1, R26.1, U1.1, U1.10, U1.22, U1.33, U1.42, U1.43, U1.44, U1.48, U1.49, U5.8, U14.2, U14.4, U16.1, U19.3, U19.4, U19.28, U21.3, U21.7, U21.11, U22.8, U22.13, U23.5, U23.6, U23.10, U24.2, U26.11, U26.15, U30.1, U32.1, U33.1, U34.1, U35.1, U38.1, U39.1, U39.10
vina: C19.1, U13.1, U13.12
xin: C1.1, U1.20, U4.1
xin32: C26.1, U19.27, U20.1
xout: R3.1, U1.21
xout32: C27.1, U19.26, U20.2
xta: C38.1, U26.4, U27.1
xtb: C39.1, U26.6, U27.3

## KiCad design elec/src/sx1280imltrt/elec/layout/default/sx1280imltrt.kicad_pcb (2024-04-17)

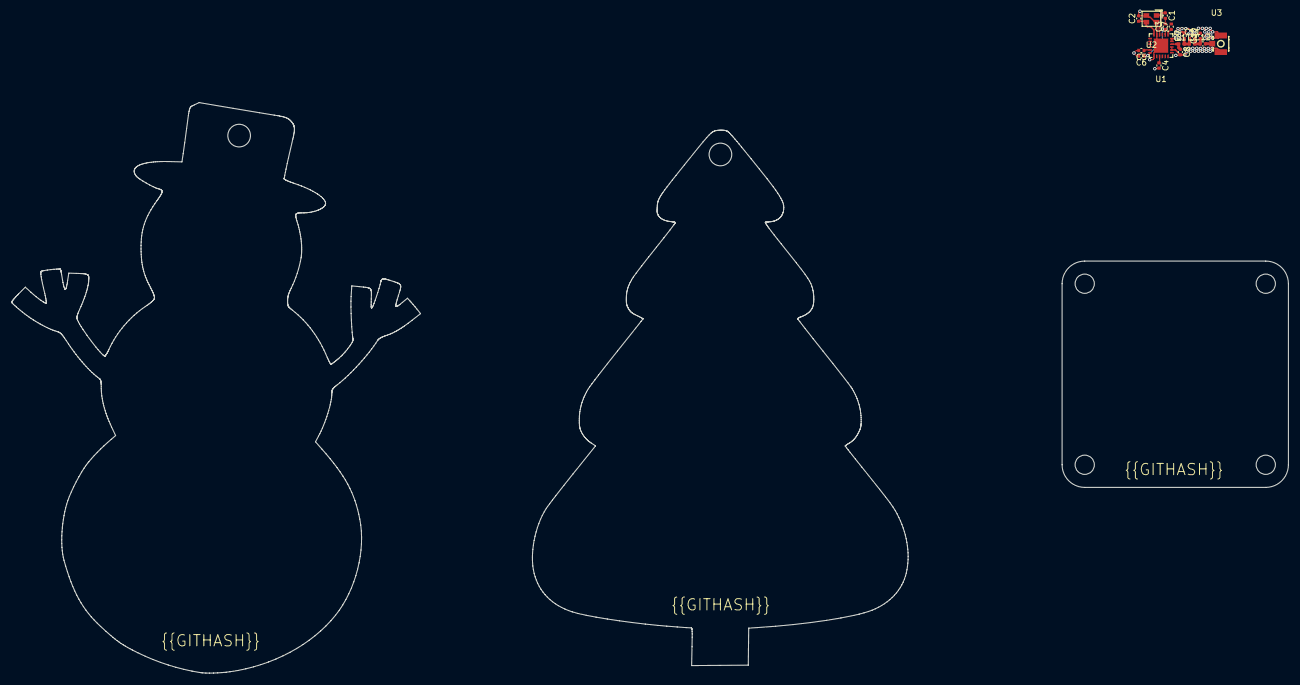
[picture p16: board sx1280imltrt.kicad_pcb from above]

Board: 2 copper layers, 17 parts (0 on the bottom side), 10 nets.

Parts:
C1, C2: 50V 11pF C0G ±5% 0402 Multilayer Ceramic Capacito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; C0402
C3: 10V 470nF X5R ±10% 0402 Multilayer Ceramic Capaci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; C0402
C4, C5: Multilayer Ceramic Capacitors MLCC - SMD/SMT 100n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; C0402
C6, C7: 50V 10nF X7R ±10% 0402 Multilayer Ceramic Capacit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; C0402
C8, C9, C10, C11: 50V 1pF C0G 0402 Multilayer Ceramic Capacitors ML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; C0402
C12: 50V 100pF C0G ±5% 0402 Multilayer Ceramic Capacit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; C0402
L1, L2: L0402
U1: QFN-24_L4.0-W4.0-P0.50-BL-EP2.6
U2: OSC-SMD_4P-L2.0-W1.6-BL
U3: IPEX-SMD_BWIPX-1-001E

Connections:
gnd: C1.2, C2.2, C3.2, C4.2, C5.2, C6.2, C7.2, C8.2, C9.2, C10.2, U1.5, U1.13, U1.20, U1.21, U1.23, U1.24, U1.25, U2.2, U2.4, U3.2, U3.3
gnd-3: C12.2, U3.1
io: C8.1, L1.1, U1.22
vcc: C7.1, U1.1
vcc-1: C3.1, C6.1, U1.2, U1.12
vcc-2: C4.1, C5.1, U1.11, U1.15
vcc-4: C9.1, C11.1, L1.2, L2.1
vcc-5: C10.1, C11.2, C12.1, L2.2
xta: C1.1, U1.4, U2.1
xtb: C2.1, U1.6, U2.3

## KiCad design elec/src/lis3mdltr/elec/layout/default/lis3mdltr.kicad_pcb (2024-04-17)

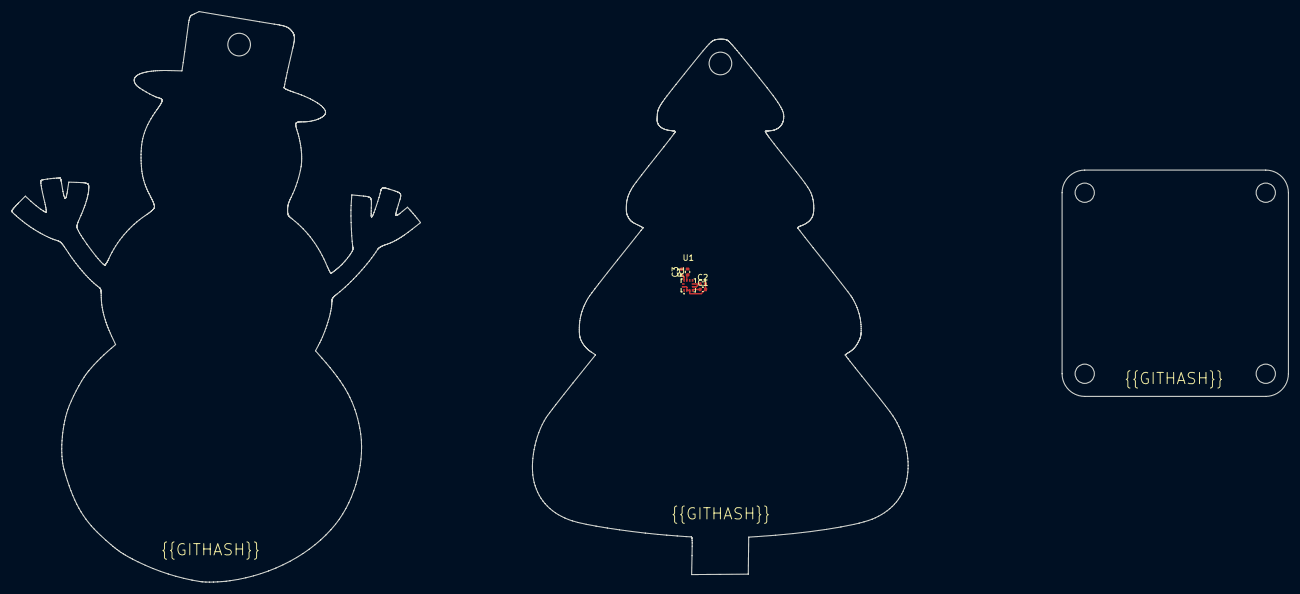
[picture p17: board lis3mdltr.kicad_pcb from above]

Board: 2 copper layers, 66.4 x 94.6 mm, 5 parts (0 on the bottom side), 4 nets.

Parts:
C1, C3: Multilayer Ceramic Capacitors MLCC - SMD/SMT 100n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; C0402
C2: Multilayer Ceramic Capacitors MLCC - SMD/SMT 1uF 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; C0402
R1: Chip Resistor - Surface Mount 1.1KOhms ±5% 1/16W 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; R0402
U1: LGA-12_L2.0-W2.0-P0.50-BL

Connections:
c1: C1.1, U1.4
gnd: C1.2, C2.2, C3.2, R1.2, U1.2, U1.3, U1.12
miso: R1.1, U1.9
vcc: C2.1, C3.1, U1.5, U1.6, U1.10

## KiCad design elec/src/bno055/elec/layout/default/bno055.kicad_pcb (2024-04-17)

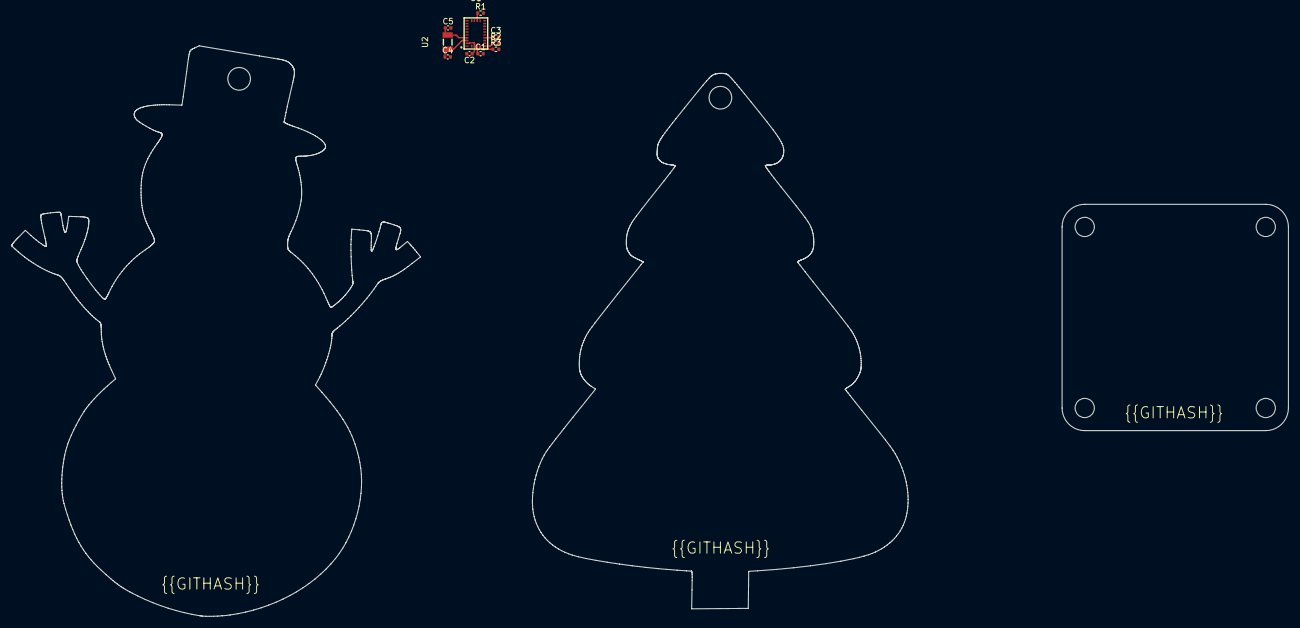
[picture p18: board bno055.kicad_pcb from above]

Board: 2 copper layers, 10 parts (0 on the bottom side), 8 nets.

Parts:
C1, C3: Multilayer Ceramic Capacitors MLCC - SMD/SMT 100n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; C0402
C2: Multilayer Ceramic Capacitors MLCC - SMD/SMT 1uF 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; C0402
C4, C5: Multilayer Ceramic Capacitors MLCC - SMD/SMT 20pF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; C0402
R1, R2, R3: Chip Resistor - Surface Mount 10KOhms ±5% 1/16W 0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; R0402
U1: LGA-28_L5.2-W3.8-P0.50-BL
U2: FC-135R_L3.2-W1.5

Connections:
cap: C3.1, U1.9
com3: R1.1, U1.17
gnd: C1.2, C2.2, C3.2, C4.2, C5.2, R1.2, R2.2, R3.2, U1.2, U1.10, U1.15, U1.16, U1.18, U1.25
ps0: R2.1, U1.6
ps1: R3.1, U1.5
vcc: C1.1, C2.1, U1.3, U1.4, U1.28
xin32: C4.1, U1.27, U2.1
xout32: C5.1, U1.26, U2.2

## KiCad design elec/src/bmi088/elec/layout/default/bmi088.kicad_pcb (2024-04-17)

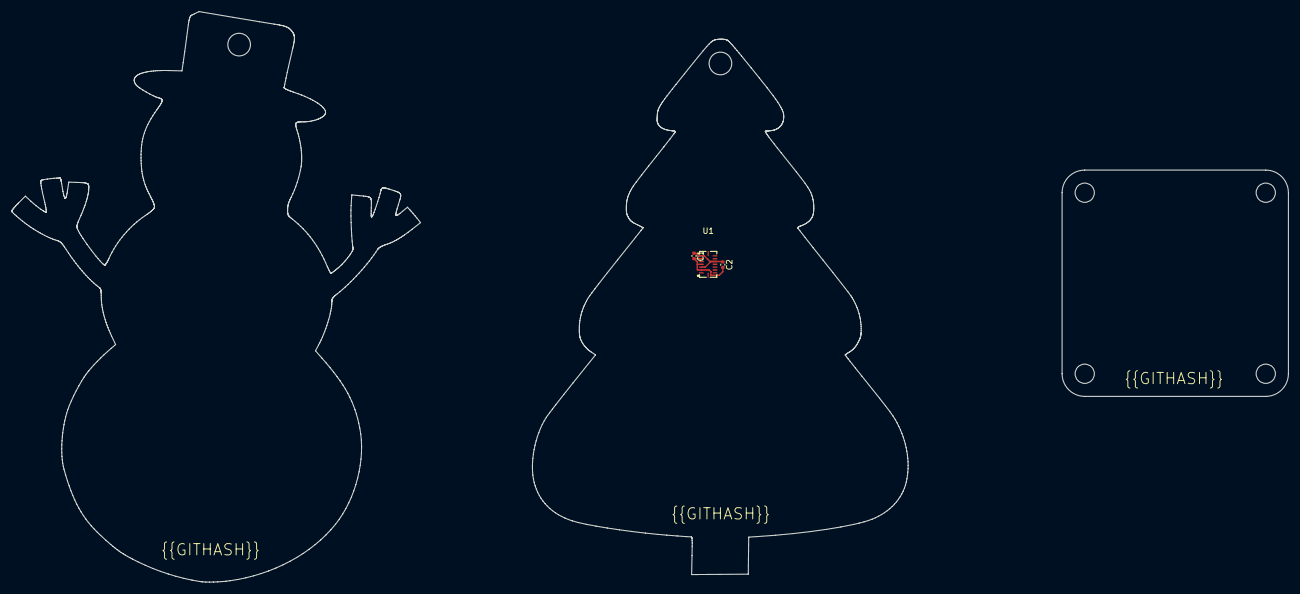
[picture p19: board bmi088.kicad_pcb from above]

Board: 2 copper layers, 66.4 x 94.6 mm, 3 parts (0 on the bottom side), 3 nets.

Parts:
C1, C2: Multilayer Ceramic Capacitors MLCC - SMD/SMT 100n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; C0402
U1: LGA-16_L4.5-W3.0-P0.50-BL

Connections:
gnd: C1.2, C2.2, U1.2, U1.4, U1.6
sdo2: U1.10, U1.15
vcc: C1.1, C2.1, U1.3, U1.7, U1.11

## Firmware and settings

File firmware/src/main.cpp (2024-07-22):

#include "../lib/RotationMath/RotationMath.hpp"

#include <Arduino.h>
#include "main.h"
#include <Wire.h>
#include <Adafruit_LIS3MDL.h>
#include <Adafruit_MPU6050.h>
#include <Adafruit_Sensor.h>
#include <SensorFusion.h>
#include "Adafruit_DRV2605.h"

#include "../lib/LED/LED.hpp"

#include "../lib/RCMapper/rcmapper.hpp"
#include "../lib/PPM/PPMController.hpp"

// constants
#define LONG_PRESS_TIME 2000 // Long press duration in milliseconds

// Sensors
Adafruit_LIS3MDL mag;
Adafruit_MPU6050 mpu;

// Haptic Driver
Adafruit_DRV2605 haptic;

// Sensor Fusion
SF fusion;

LED led;
RotationMath rotation_math;

PPMController ppm_controller;

// Variables
float gx, gy, gz, ax, ay, az, mx, my, mz;
float pitch, roll, yaw, throttle;
float deltat;
volatile int flightMode = 1; // Starts at mode 1
unsigned long buttonPressTime = 0;
bool buttonState = false;
bool lastButtonState = false;
bool deviceState = false;

float getThrottle() {
  int rawValue = analogRead(A0); // Assuming A0 is the throttle input pin
  float throttle = map(rawValue, 730, 200, 0, 100);
  throttle = constrain(throttle, 0, 100); // Ensuring throttle stays within bounds
  return throttle;
}

void changeFlightMode() {
  // Function to change the flight mode of the drone
  // This function is called when the MENU button is pressed
  // It cycles through the flight modes (1, 2, 3) and updates the LEDs accordingly
  static unsigned long lastChangeTime = 0;
  unsigned long currentTime = millis();
  if (currentTime - lastChangeTime < 200) {
    return; // Exit the function if it's been less than 200ms since the last change
  }
  lastChangeTime = currentTime; // Update the last change time
  flightMode = flightMode % 3 + 1; // Cycles through 1, 2, 3 and wraps around
  led.updateLEDs(deviceState, flightMode);
  Serial.println("save");

  float* quat = fusion.getQuat();
  rotation_math.setZeroQuaternion(matrix::Quatf(fusion.getQuat()));
}

void nonBlockingButtonCheck() {
  // Starts a timer if button is pressed, resets if released
  buttonState = digitalRead(POWER_BUTTON_PIN);
  // Serial.print("Button state: "); Serial.println(buttonState ? "HIGH" : "LOW");

  // if the button is being pressed, and the timer is not running, start the timer
  if (buttonState == LOW) {
    Serial.println("Button is pressed.");
    if (buttonPressTime == 0){
      buttonPressTime = millis();
      Serial.println("Timer started.");
    }
    else if (millis() - buttonPressTime > LONG_PRESS_TIME) {
      // If the button is pressed for LONG_PRESS_TIME, toggle the device state
      deviceState = !deviceState;
      Serial.print("Device state toggled to: "); Serial.println(deviceState ? "ON" : "OFF");
      buttonPressTime = 0;
    }
    else {
      // update the led strip based on the percentage of time the button has been pressed
      int percentage = (millis() - buttonPressTime) * 100 / LONG_PRESS_TIME;
      Serial.print("Button hold percentage: "); Serial.println(percentage);
      led.animatePowerOn(percentage, deviceState);
    }
  }
  // else, if the button is not pressed, reset the timer to 0
  else if (buttonState == HIGH) {
    if (buttonPressTime != 0) {
      Serial.println("Button released. Timer reset.");
    }
    buttonPressTime = 0;
  }

  lastButtonState = buttonState;
}


void setup() {
  // Setup Serial
  Serial.begin(115200);
  led.setup();
  led.updateLEDs(deviceState, flightMode);

  // Setup Buttons
  pinMode(MENU_BUTTON_PIN, INPUT_PULLUP); // Set the button pin as input with pull-up
  attachInterrupt(digitalPinToInterrupt(MENU_BUTTON_PIN), changeFlightMode, FALLING); // Attach interrupt for button press


  // // Setup I2C
  Wire.setSCL(I2C_SDA_PIN);
  Wire.setSDA(I2C_SCL_PIN);

  Wire.begin();

  mag.begin_I2C(LIS3MDLTR_ADDRESS, &Wire);
  mpu.begin(MPU6050_ADDRESS, &Wire);

  ppm_controller.initialize(PPM_PIN);
}

void loop() {
  nonBlockingButtonCheck();
  led.updateLEDs(deviceState, flightMode);

  if (!deviceState) {
    Serial.println("Device is powered off.");
    return;
  }


  mag.read();
  sensors_event_t a, g, temp;
  mpu.getEvent(&a, &g, &temp);


  deltat = fusion.deltatUpdate();
  // the chips are in different orientation. Following both of those
  // mag datasheet: https://www.mouser.com/datasheet/2/389/lis3mdl-1849592.pdf
  // mpu datasheet: https://www.cdiweb.com/datasheets/invensense/mpu_6500_rev1.0.pdf
  fusion.MahonyUpdate(g.gyro.x, g.gyro.y, g.gyro.z, a.acceleration.x, a.acceleration.y, a.acceleration.z, deltat);

  // pitch = fusion.getPitch();
  // roll = fusion.getRoll();    //you could also use getRollRadians() ecc
  // yaw = fusion.getYaw();
  throttle = getThrottle();

  float* quat = fusion.getQuat();
  matrix::Eulerf control_angles = rotation_math.getControlAngles(matrix::Quatf(quat));
  // Serial.print(">dt:");
  // Serial.println(deltat);
  // Serial.print(">gx:");
  // Serial.println(g.gyro.x);
  // Serial.print(">gy:");
  // Serial.println(g.gyro.y);
  // Serial.print(">gz:");
  // Serial.println(g.gyro.z);
  // Serial.print(">ax:");
  // Serial.println(a.acceleration.x);
  // Serial.print(">ay:");
  // Serial.println(a.acceleration.y);
  // Serial.print(">az:");
  // Serial.println(a.acceleration.z);
  // Serial.print(">mx:");
  // Serial.println(mag.x);
  // Serial.print(">my:");
  // Serial.println(mag.y);
  // Serial.print(">mz:");
  // Serial.println(mag.z);
  // Serial.print(">Throttle:\t"); Serial.println(throttle);
  // Serial.println();
  // print the quaternion
  // Serial.print(">w:");
  // Serial.println(quat[0]);
  // Serial.print(">x:");
  // Serial.println(quat[1]);
  // Serial.print(">y:");
  // Serial.println(quat[2]);
  // Serial.print(">z:");
  // Serial.println(quat[3]);

  // Serial.print(">Roll: ");
  // Serial.println(degrees(control_angles(0)));
  // Serial.print(">Pitch: ");
  // Serial.println(degrees(control_angles(1)));
  // Serial.print(">Yaw: ");
  // Serial.println(degrees(control_angles(2)));
  // Serial.println("");

  RCMapper mapper;

  // Create a test input frame
  inputFrameControlSignals input_frame;
  input_frame.control_angles = control_angles;
  input_frame.throttle = 1000; // Example throttle value
  input_frame.additional_channels[0] = 1000;
  input_frame.additional_channels[1] = 1000;
  input_frame.additional_channels[2] = 1000;
  input_frame.additional_channels[3] = 1000;

  // Map values using the mapper
  ControlSignals output_signals = mapper.mapValues(input_frame);

  ppm_controller.setPPMValues(output_signals);

  Serial.print("Yaw: ");
  Serial.println(output_signals.yaw);
  Serial.print("Pitch: ");
  Serial.println(output_signals.pitch);
  Serial.print("Roll: ");
  Serial.println(output_signals.roll);
  Serial.print("Throttle: ");
  Serial.println(output_signals.throttle);

  delay(100);
}

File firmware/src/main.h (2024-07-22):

// I2C Connections
#define I2C_SDA_PIN 21
#define I2C_SCL_PIN 20

// UART Connections
#define UART_TX_PIN 4
#define UART_RX_PIN 5

// GPIO Connections
#define INTERRUPT_PIN 24
#define POWER_BUTTON_PIN 13
#define MENU_BUTTON_PIN 12
#define HALL_SENSOR_PIN 26
#define CHARGE_STATUS_PIN 17
#define PPM_PIN 4

// I2C Addresses
#define BNO055_ADDRESS 0x28
#define BMI088_ADDRESS_ACC 0x18
#define BMI088_ADDRESS_GYRO 0x69
#define LIS3MDLTR_ADDRESS 0x1C
#define MPU6050_ADDRESS 0x68
#define DRV2605_ADDRESS 0x5A

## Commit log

2024-02-15 Configure project
    [swoop.kicad_pcb, swoop.kicad_sch]
2024-02-17 ios cleanup
    [debug.kicad_pcb, debug.kicad_sch, swoop.kicad_pcb]
2024-02-17 layout 80% complete
    [debug.kicad_pcb, swoop.kicad_pcb]
2024-02-18 layout 95%
    [debug.kicad_pcb]
2024-02-18 layout complete
    [debug.kicad_pcb]
2024-02-29 added equation support
    [debug.kicad_pcb]
2024-03-01 Get the popped IMU running
2024-03-07 Update radio to use ESP32 rather than STM32
2024-03-19 fixing esp32 import
    [debug.kicad_pcb, debug.kicad_sch, swoop.kicad_pcb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]
2024-03-19 testing new CI with kicad8
2024-04-17 adding deps locally
    [ah3772-sa-7.kicad_pcb, ah3772-sa-7.kicad_sch, ams1117-33.kicad_pcb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]
2024-04-27 merging in layouts (#20)
    * merging in layouts
    * cleaner commit
    * remove test container from ci job
    * fix missing V in physical
    * increase i_q for it to solve
    ---------
    [debug.kicad_pcb, drv5053raqdbzr.kicad_pcb, drv5053raqdbzr.kicad_sch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]
2024-04-29 Process flow diagram (#22)
2024-06-03 platformio: force FastLED to exactly version 3.6
    From 3.7 on there is an issue with the addLeds function producing `Error: invalid offset, value too big` compile errors.
    See https://github.com/earlephilhower/arduino-pico/discussions/1649
2024-06-03 Move LED logic into separate class
    The button dependency should still move out.
